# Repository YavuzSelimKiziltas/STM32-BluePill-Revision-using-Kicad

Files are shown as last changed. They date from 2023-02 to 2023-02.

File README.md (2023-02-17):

# STM32 BluePill Revision using Kicad
 Kicad PCB Files for STM32 BluePill Project 
 
 This PCB is drawn from the **Phil's Lab** youtube channel. Click [here](https://youtu.be/aVUqaB0IMh4) to watch the video: <br/>

 ### Information about PCB:
 PCB dimensions are 42x42 mm. <br/>
 Bottom layer is used as a power plane and connected to the GND to reduce impedance. <br/>
 An SPDT switch is used to manually activate bootloader. <br/>
 120R Ferrite Bead is used to filter high frequency noise around 100MHz. <br/> 
 
 ### Used Materials:
 3 x (1x4) Male Headers <br/>
 1 x STM32F103C8T6 MCU <br/> 
 1 x 16 MHz Crystak Oscillator <br/ 
 1 x AMS1117-3.3 linear voltage regulator <br/>
 1 x Type-B Micro female USB port  <br/>
 4 x 1k5 1206 SMD Resistor  <br/>
 1 x 10k 1206 SMD Resistor <br/>
 2 x 22uF 1206 SMD Capacitor <br/>
 5 x 100nF 1206 SMD Capacitor <br/>
 2 x 10pF 1206 SMD Capacitor <br/>
 2 x 1uF 1206 SMD Capacitor <br/>
 1 x 10nF 1206 SMD Capacitor <br/>
 1 x 0805 RED LED <br/>
 1 x SDPT Button switch <br/>
 1 x 120R Ferrite bead <br/>
 
 ## PCB Board and Schematic Images:
 ### Schematics of the Circuit Diagram:
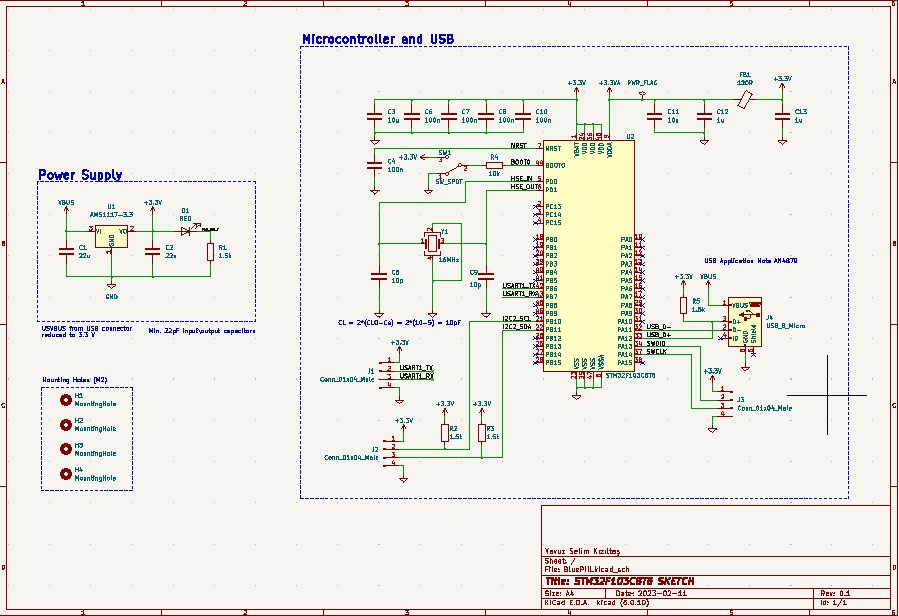
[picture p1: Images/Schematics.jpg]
 
 ### PCB Layout and Routing:
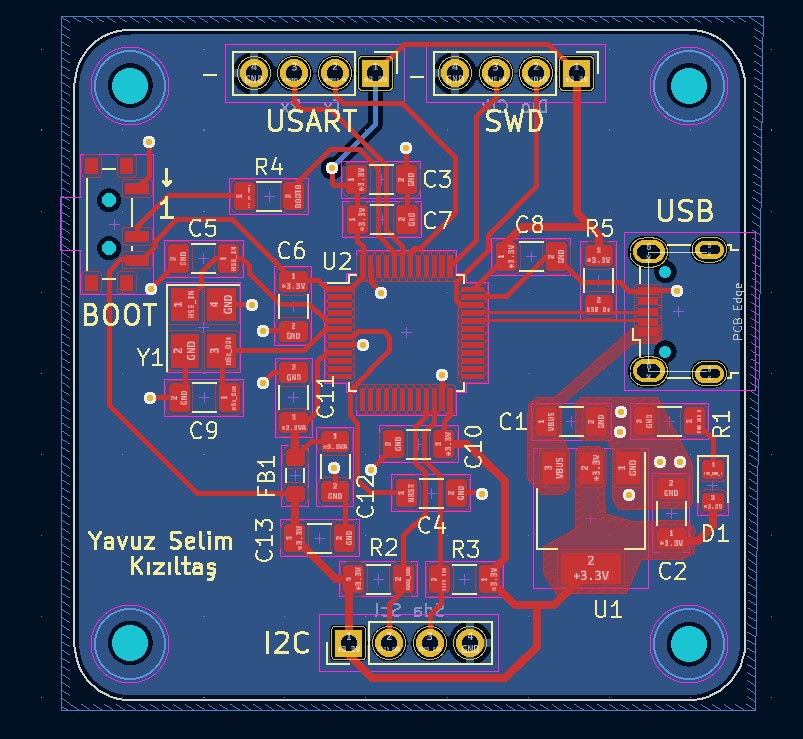
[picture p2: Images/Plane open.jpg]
 
 ### Top Layer of the 3D PCB Board:
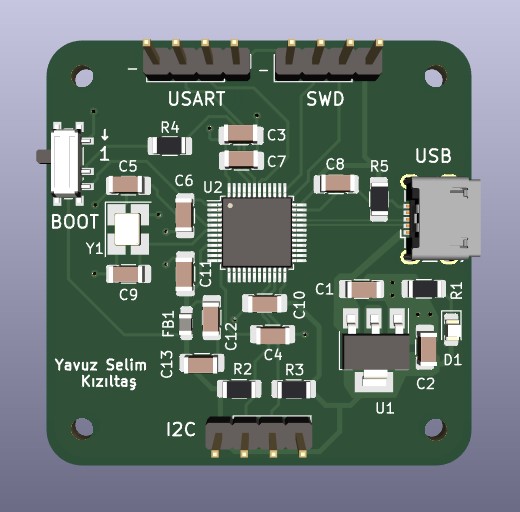
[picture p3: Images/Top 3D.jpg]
 
 ### Bottom Layer of the 3D PCB Board:
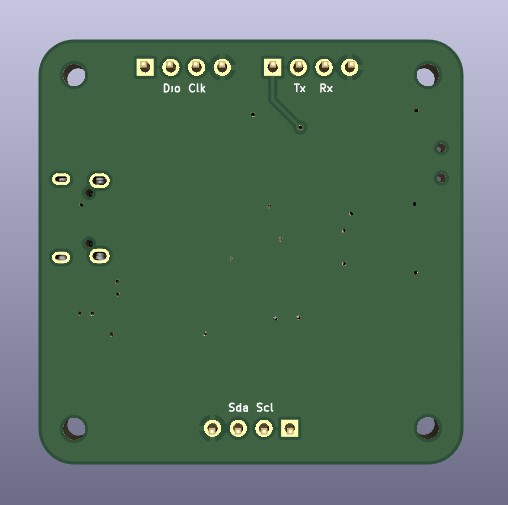
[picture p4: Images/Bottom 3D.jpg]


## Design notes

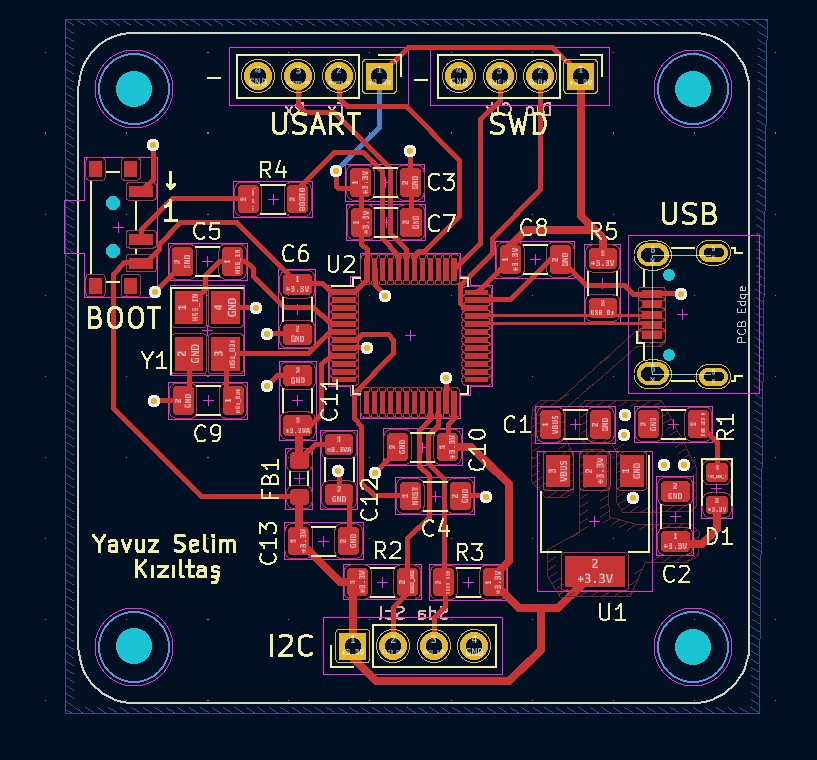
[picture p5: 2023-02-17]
Images/Top Routing.jpg

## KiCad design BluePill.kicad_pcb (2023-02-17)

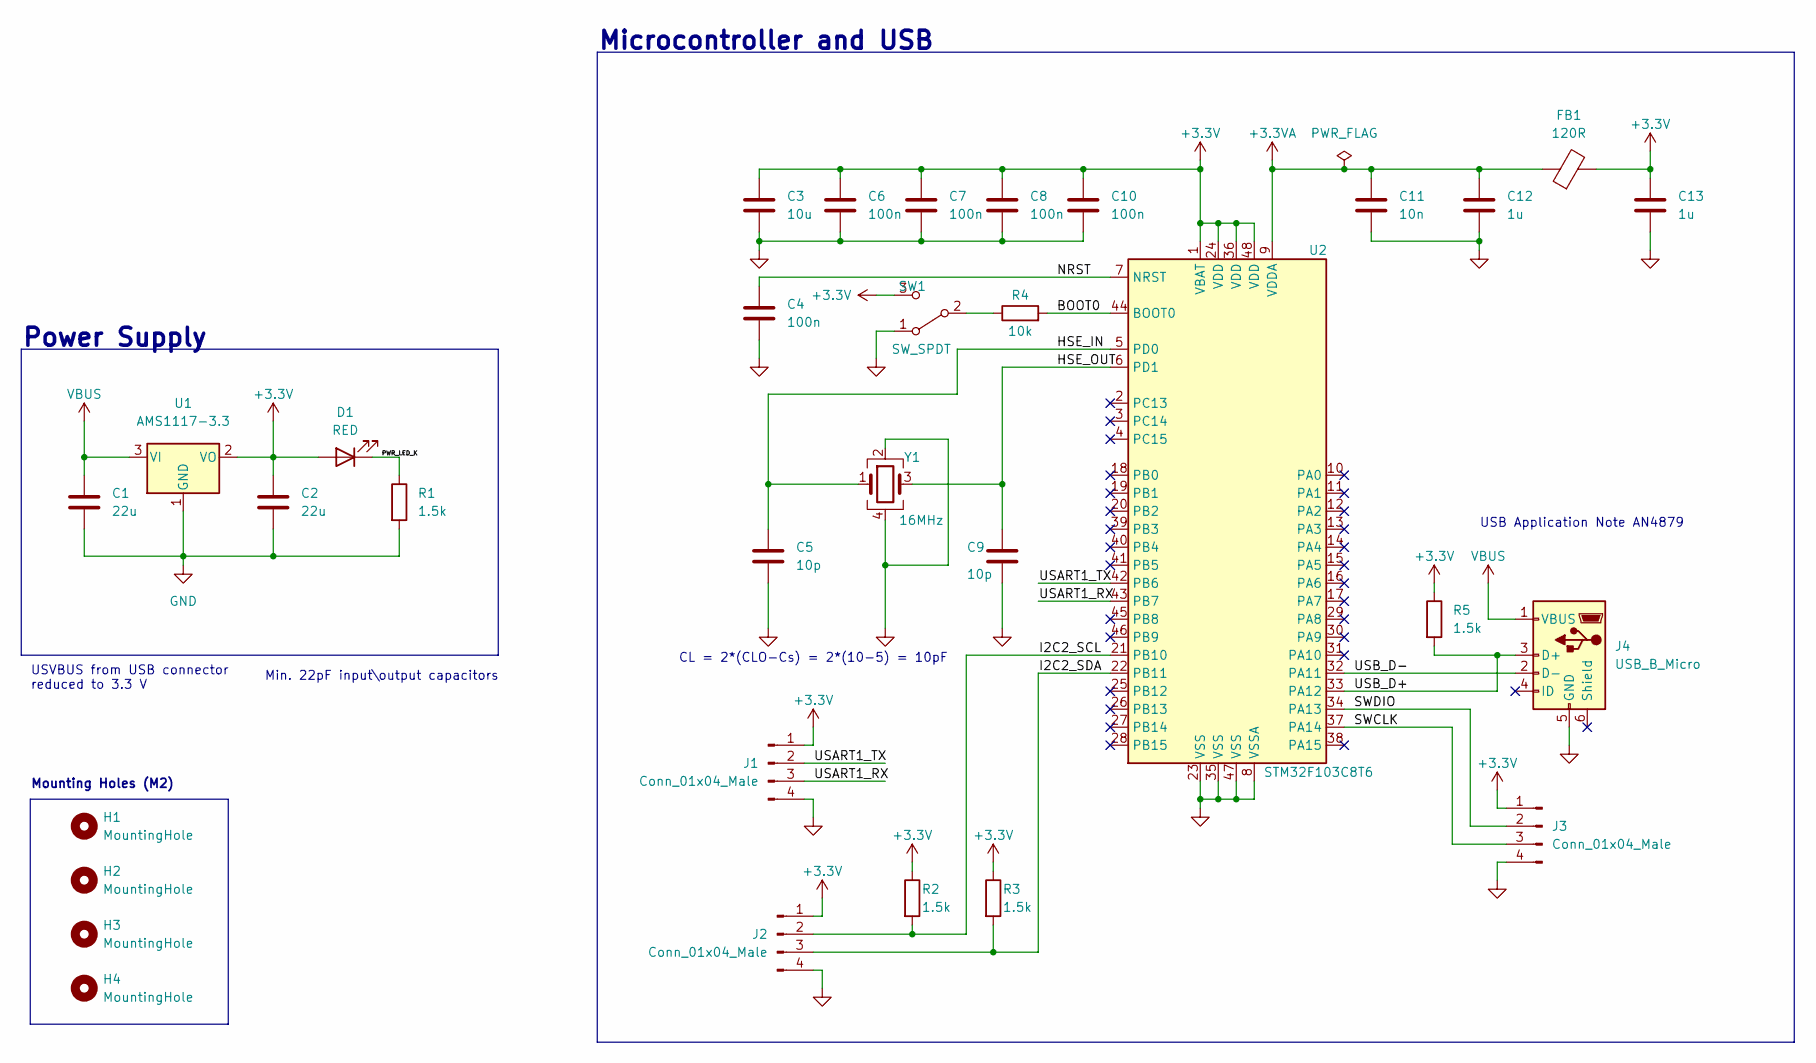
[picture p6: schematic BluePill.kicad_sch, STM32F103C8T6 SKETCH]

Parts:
C1, C2: 22u; C_1206_3216Metric_Pad1.33x1.80mm_HandSolder
C3: 10u; C_1206_3216Metric_Pad1.33x1.80mm_HandSolder
C4, C6, C7, C8, C10: 100n; C_1206_3216Metric_Pad1.33x1.80mm_HandSolder
C5, C9: 10p; C_1206_3216Metric_Pad1.33x1.80mm_HandSolder
C11: 10n; C_1206_3216Metric_Pad1.33x1.80mm_HandSolder
C12, C13: 1u; C_1206_3216Metric_Pad1.33x1.80mm_HandSolder
D1: RED; LED_0805_2012Metric_Pad1.15x1.40mm_HandSolder
FB1: 120R; L_0805_2012Metric_Pad1.05x1.20mm_HandSolder
H1, H2, H3, H4: MountingHole; MountingHole_2.2mm_M2
J1, J2, J3: Conn_01x04_Male; PinHeader_1x04_P2.54mm_Vertical
J4: USB_B_Micro; USB_Micro-B_Wuerth_629105150521
R1, R2, R3, R5: 1.5k; R_1206_3216Metric_Pad1.30x1.75mm_HandSolder
R4: 10k; R_1206_3216Metric_Pad1.30x1.75mm_HandSolder
SW1: SW_SPDT; SW_SPDT_PCM12
U1: AMS1117-3.3; SOT-223-3_TabPin2
U2: STM32F103C8T6; LQFP-48_7x7mm_P0.5mm
Y1: 16MHz; Crystal_SMD_3225-4Pin_3.2x2.5mm_HandSoldering

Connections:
+3.3V: C2.1, C3.1, C6.1, C7.1, C8.1, C10.1, C13.1, D1.2 (A), FB1.2, J1.1, J2.1, J3.1, R2.1, R3.1, R5.1, SW1.3 (C), U1.2 (VO), U2.1 (VBAT), U2.24 (VDD), U2.36 (VDD), U2.48 (VDD)
+3.3VA: C11.1, C12.1, FB1.1, U2.9 (VDDA)
/BOOT0: R4.2, U2.44 (BOOT0)
/HSE_IN: C5.1, U2.5 (PD0), Y1.1
/HSE_OUT: C9.1, U2.6 (PD1), Y1.3
/I2C2_SCL: J2.2, R2.2, U2.21 (PB10)
/I2C2_SDA: J2.3, R3.2, U2.22 (PB11)
/NRST: C4.1, U2.7 (NRST)
/PWR_LED_K: D1.1 (K), R1.1
/SWCLK: J3.3, U2.37 (PA14)
/SWDIO: J3.2, U2.34 (PA13)
/USART1_RX: J1.3, U2.43 (PB7)
/USART1_TX: J1.2, U2.42 (PB6)
/USB_D+: J4.3 (D+), R5.2, U2.33 (PA12)
/USB_D-: J4.2 (D-), U2.32 (PA11)
GND: C1.2, C2.2, C3.2, C4.2, C5.2, C6.2, C7.2, C8.2, C9.2, C10.2, C11.2, C12.2, C13.2, J1.4, J2.4, J3.4, J4.5 (GND), R1.2, SW1.1 (A), U1.1 (GND), U2.8 (VSSA), U2.23 (VSS), U2.35 (VSS), U2.47 (VSS), Y1.2, Y1.4
unnamed: R4.1, SW1.2 (B)
VBUS: C1.1, J4.1 (VBUS), U1.3 (VI)

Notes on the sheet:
Microcontroller and USB
USVBUS from USB connector reduced to 3.3 V
CL = 2*(CLO-Cs) = 2*(10-5) = 10pF
Mounting Holes (M2)
Power Supply
Min. 22pF input\output capacitors
USB Application Note AN4879

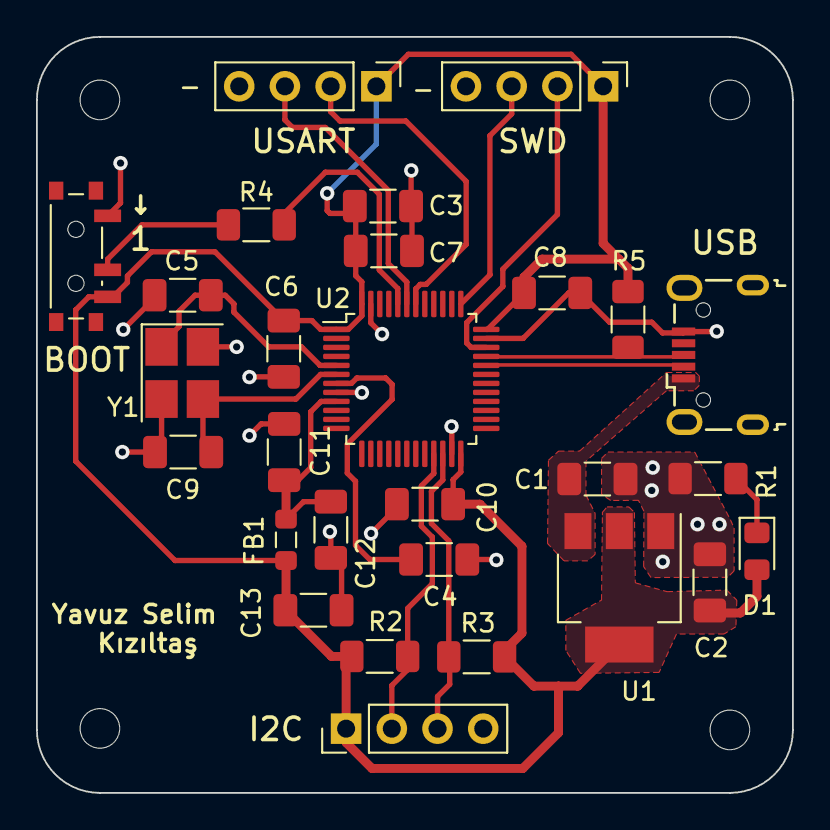
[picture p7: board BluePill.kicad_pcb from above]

Board: 2 copper layers, 42.0 x 42.0 mm, 32 parts (0 on the bottom side), 18 nets.
